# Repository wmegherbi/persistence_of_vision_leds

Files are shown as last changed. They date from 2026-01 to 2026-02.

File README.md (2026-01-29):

# persistence_of_vision_leds
Ce projet a pour objectif de concevoir et réaliser un système d’affichage basé sur la persistance rétinienne sur une barre de LEDs en rotation. En exploitant la persistance rétinienne de l’œil humain, le système permet d’afficher des images fixes ou animées dans l’espace à partir d’un nombre limité de LEDs disposées sur une structure rotative.

Ce projet se divise en trois parties différentes : 
- Partie Mécanique : plans et schémas du système complet ainsi que des impressions 3D 
- Partie LEDs : contrôle, alimentation des LEDs et traitement d'image via la Raspberry Pi située dans la partie rotative
- Partie Moteur : contrôle, alimentation du moteur et mise en place de l'interface de contrôle du moteur via la Raspberry Pi située dans la partie statique

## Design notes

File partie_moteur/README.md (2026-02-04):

# PARTIE MOTEUR

## Contrôle moteur et mesure de vitesse par capteur Hall (Raspberry Pi)

Ce projet permet de :
- piloter un moteur via PWM (50 Hz)
- mesurer la vitesse de rotation avec un capteur à effet Hall
- générer une impulsion matérielle '1 tour' sur un GPIO
- superviser le système via une interface web

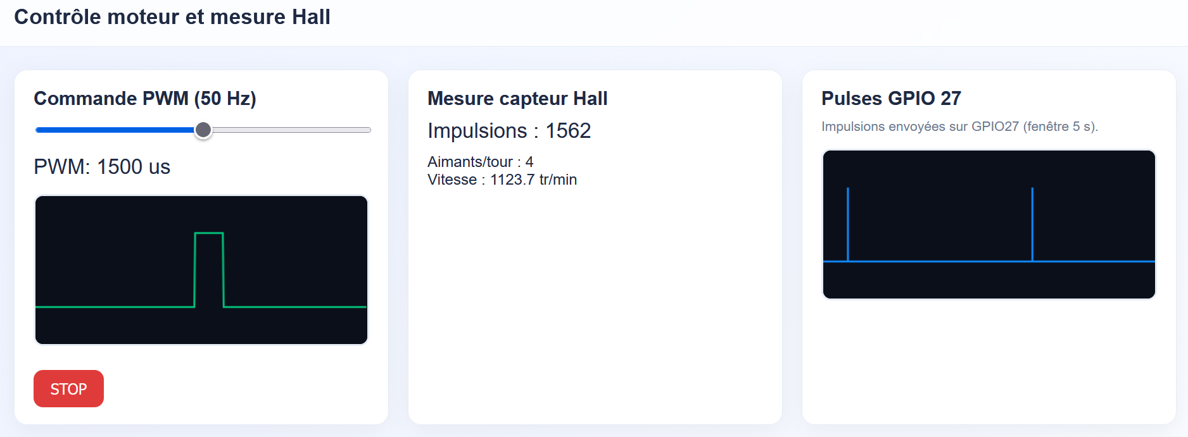
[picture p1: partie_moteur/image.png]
Interface de contrôle


---
## Table des matières

1. [Architecture](#architecture)
2. [Matériel requis](#matériel-requis)
   - [Connexions GPIO](#connexions-gpio)
3. [Installation](#installation)
   - [Installer pigpio](#installer-pigpio)
   - [Installer les dépendances Python](#2-installer-les-dependances-python)
4. [Utilisation](#utilisation)
   - [Lancer le programme](#lancer-le-programme)
   - [Accéder à l'interface web](#acceder-a-linterface-web)
5. [Fonctionnalités détaillées](#fonctionnalités)
6. [Fonctionnement interne](#fonctionnement-interne-résumé)
7. [Remarques](#remarques)

## Architecture

- pigpiod : gestion temps réel des GPIO (PWM)
- Python :  contrôle et géstion des données
- Flask : serveur web
- HTML / JavaScript : interface web

```` bash
partie_moteur/
├── web3_control.py    # Cœur du système : contrôle moteur, gestion capteur Hall, API Flask
├── static/
│   ├── app.js          # Logique front-end (graphiques, interactions)
│   └── style.css       # Styles de l'interface utilisateur
└── templates/
    └── index.html      # Template HTML principal (interface de contrôle)
````
---

## Matériel requis

### Composants principaux
- **Raspberry Pi** avec **Raspberry Pi OS** 
- **Capteur à effet Hall** (ex: US5881, A3144 ou DRV5055) pour la détection des tours
- **Moteur brushless A2212 930KV** + **ESC 30A** (compatible PWM 50Hz)
- **Aimants**  à fixer sur roue pour déclencher le capteur Hall

### Connexions GPIO

| GPIO Raspberry Pi | Fonction | Détails |
|---|---|---|
| GPIO 18 | Sortie PWM (commande moteur)  | Connecté à l'entrée PWM de l'ESC |
| GPIO 17 | Entrée capteur Hall | Configuré pour détecter les fronts |
| GPIO 27 | Sortie impulsion "1 tour" | Génère une impulsion de 100 µs à chaque tour complet du moteur |

---

## Installation

### Installer pigpio

```bash
sudo apt update
sudo apt install pigpio python3-pigpio
sudo pigpiod
```

### 2) Installer les dependances Python

```bash
pip3 install flask pigpio
```

## Utilisation

### Lancer le programme :

```bash
python3 web3_control.py
````

### Accéder à l'interface web :

```bash
http://<IP_DU_RASPBERRY>:5000
````

## Fonctionnalités

- Slider PWM (1000–2000 µs)
- Bouton STOP

Affichage :
- nombre d'impulsions Hall
- nombre d'aimants par tour
- vitesse en tr/min
- visualisation PWM et impulsions '1 tour'

## Fonctionnement interne (résumé)

- Les fronts du capteur Hall sont traités par un callback pigpio
- Les données partagées sont protégées par un lock (thread safety)
- La vitesse est calculée via une fenêtre glissante de timestamps de 5 secondes
- Une impulsion courte (100 µs) est générée sur GPIO27 à chaque tour complet (quand 4 fronts sont déctetés du capteur effet hall)

### Flux de Données
1. **Capteur Hall → Raspberry Pi** :
   - Détection des fronts via `pigpio.callback()` (dans `web3_control.py`)
   - Stockage des timestamps dans `edge_times[]`

2. **Raspberry Pi → Interface Web** :
   - Données exposées via les endpoints Flask :
     - `/api/hall` (compteur, RPM)
     - `/api/pulse` (timestamps des impulsions)
   - Mise à jour en temps réel via JavaScript (`static/app.js`)

3. **Interface Web → Moteur** :
   - Contrôle PWM via le slider (POST sur `/set_live`)
   - Arrêt d'urgence (POST sur `/stop`)

## Remarques

- pigpiod doit être lancé avant le script
``` bash
sudo pigpiod
```

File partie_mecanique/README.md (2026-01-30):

# PARTIE MECANIQUE

### Pièce 3D
Les pièces 3D ont été modélisées via Onshape, et disponible au format STL.

Stator : 
- ``main.stl`` support principal fixé à un trépied. 

Rotor : 
- ``petite_roue.stl`` roue dentée fixée au moteur. 
- ``grande_roue.stl`` roue principale.  
- ``couvercle.stl`` fixé à la grande roue. 
- [courroie](https://www.amazon.fr/sourcing-map-Courroie-distribution-caoutchouc/dp/B0DSR3P59V/ref=sr_1_4?__mk_fr_FR=ÅMÅŽÕÑ&crid=2DVCB6ZJ2Z6N6&dib=eyJ2IjoiMSJ9.INokD1g1XKGq4FjiK4KJ-2DFuZPBLBakq1pM_ikAQQW-i8_wvu6zflLYD9bUancVo1O1l0KUpVF_Tc12299VBfvdVWGJqAfd7dZ5Z0dowRu1OleMIxkBsCXyfrw_BsMGcycEjID_bXYTH-4Jm1so129zpuPP06CmUVDd1TbQXxbmJKklR36qcrfXnCtGEjsZ-37gbQdMV0VhXsDEZqvy0kOxExp_DtmuPP1F3U7picrk7hs-b8qVLdveGdYnYE3JuToG5yF9XXBt19ypSJsxIJoUYEDpVoUJI-cyxjdedZ8.aslACeUXgRTCYPRULSt5mBXesOI6mXxBFWhpa6HJw2Y&dib_tag=se&keywords=courroie+dentée+pas+5+mm+610+mm&qid=1767950807&sprefix=courroie+dentée+pas+5+mm+6010+mm%2Caps%2C284&sr=8-4) pour la transmission. 

## Description du support

``main`` est le support principal qui s'attache au trépied. La pièce est sous-dimensionnée volontairement au niveau du trépied afin d'assurer une meilleur stabilité, il est normal qu'il faille forcer légèrement pour la rentrer dans le trépied. 
Au dos de la pièce il y a un emplacement pour la carte Raspberry Pi qui contrôle le moteur, des emplacements sont prévus pour visser la carte. 
Le moteur se place en bas dans son emplacement prévu, Il se visse par l'arrière, les espacements entre les vis ne sont pas les mêmes horizontalement et verticalement, vérifiez le sens. 
Le capteur à effet Hall est collé sur le côté de la pièce afin de ne pas gêné les câbles et être suffisament près des aimants placés sur la roue. 

#### Support d'axe

Le support d'axe correspond à la partie supérieur de la pièce. Ce tube acceuille des [roulements à billes](https://www.123roulement.com/roulement-palier/roulement-bille/simple-rangee/6005-2rsh-skf) de diamètre intérieur 25 mm et 47 mm de diamètre extérieur. Pour assurer que les roulements à billes ne glisse pas hors du support pendant que le système est en marche il faut ajouter des vis dans les trous creusés sur le dessus de la pièce. Le slip ring se fixe au dos du support d'axe. 

## Transmission mécanique
La ``petite_roue`` est fixée au moteur et entraîne la [courroie](https://www.amazon.fr/sourcing-map-Courroie-distribution-caoutchouc/dp/B0DSR3P59V/ref=sr_1_4?__mk_fr_FR=ÅMÅŽÕÑ&crid=2DVCB6ZJ2Z6N6&dib=eyJ2IjoiMSJ9.INokD1g1XKGq4FjiK4KJ-2DFuZPBLBakq1pM_ikAQQW-i8_wvu6zflLYD9bUancVo1O1l0KUpVF_Tc12299VBfvdVWGJqAfd7dZ5Z0dowRu1OleMIxkBsCXyfrw_BsMGcycEjID_bXYTH-4Jm1so129zpuPP06CmUVDd1TbQXxbmJKklR36qcrfXnCtGEjsZ-37gbQdMV0VhXsDEZqvy0kOxExp_DtmuPP1F3U7picrk7hs-b8qVLdveGdYnYE3JuToG5yF9XXBt19ypSJsxIJoUYEDpVoUJI-cyxjdedZ8.aslACeUXgRTCYPRULSt5mBXesOI6mXxBFWhpa6HJw2Y&dib_tag=se&keywords=courroie+dentée+pas+5+mm+610+mm&qid=1767950807&sprefix=courroie+dentée+pas+5+mm+6010+mm%2Caps%2C284&sr=8-4) qui entraîne la ``grande_roue``. Le ``couvercle`` est vissé sur la grande roue et tient les profilés en aluminium avec [les bandeaux de LEDs](https://fr.aliexpress.com/item/4001201679511.html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€%216%2C79€%21%21%21%21%21%40211b61bb17643396735751664eb65b%2110000015284474061%21btfpre%21%21%21%211%210%21&afTraceInfo=4001201679511__pc__c_ppc_item_bridge_pc_main__rdjCUwP__1764339673682&gatewayAdapt=glo2fra). Le rapport de réduction entre les roues est d'environ 8.5. 

Courroie :
* Longueur: 610 mm
* Largeur: 15 mm
* Pas: 5 mm

Petite Roue : 
* Diamètre: 19 mm (à l'extérieur des dents)
* Largeur: 30 mm
* Pas: 5 mm

Grande roue : 
* Diamètre: 161 mm (à l'extérieur des dents)
* Largeur: 22 mm
* Pas: 5 mm
* Longueur de l'axe de rotation: 84.4 mm

L'axe de rotation est percé afin d'acceuillir les câbles sortant du slip ring. Ces câbles servent à l'alimentation de la carte Raspberry Pi et des bandeaux de LEDs ainsi que la transmission du signal généré par le capteur à effet Hall. La carte Raspberry Pi est vissé dans le compartiment au centre de la roue.

Le ``couvercle`` recouvre la Raspberry Pi de la grande roue, il est troué pour laisser les câbles qui font la communication entre les bandeaux de LED et la carte Raspberry Pi. [Les profilés en aluminium](https://www.leroymerlin.fr/produits/profile-u-aluminium-anodise-mat-standers-h-10-x-l-15-x-ep-1-mm-l-1-m-87477956.html) y sont vissés en son centre. Sur ces profilés sont attachés [les bandeaux de LEDs](https://fr.aliexpress.com/item/4001201679511.html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€%216%2C79€%21%21%21%21%21%40211b61bb17643396735751664eb65b%2110000015284474061%21btfpre%21%21%21%211%210%21&afTraceInfo=4001201679511__pc__c_ppc_item_bridge_pc_main__rdjCUwP__1764339673682&gatewayAdapt=glo2fra). Des serre flex permettent de maintenir les LEDs et leurs câbles sur les profilés.

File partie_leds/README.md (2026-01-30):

# Dans ce dossier, vous trouverez tout ce qu'il faut savoir pour faire fonctionner les LEDs sur le système

## Sommaire
- [Partie 1 : Connexion avec la Raspberry Pi](#partie-1--connexion-avec-la-raspberry-pi)
- [Partie 2 : Gestion des LEDs](#partie-2--gestion-des-leds)
  - [Interfaces SPI](#interfaces-spi)
  - [Remarques](#remarques)
- [Partie 3 : Comment setup une Raspberry Pi toute neuve](#partie-3--comment-setup-une-raspberry-pi-toute-neuve)

## Partie 1 : Connexion avec la Raspberry Pi

La Raspberry Pi est alimentée via le 5 V provenant du slip ring, lui-même relié à la prise secteur. Cette même alimentation alimente également les LEDs via des connecteurs situés aux quatre coins de la roue.

Pour lancer le programme sur la Raspberry Pi, on se connecte en SSH depuis un PC connecté au même réseau. Pour la première connexion, nous conseillons d’utiliser l’interface graphique de la Raspberry Pi afin de configurer les paramètres réseau (nom du réseau et mot de passe) à l’aide d’un clavier, d’une souris et d’un écran connecté en HDMI à la carte.  
Notez également l’adresse IP de la Raspberry Pi une fois connectée au réseau, afin de configurer la liaison SSH.

### Nom d’utilisateur et mot de passe
Le nom d’utilisateur et le mot de passe de cette Raspberry Pi sont respectivement :  
**nom d’utilisateur : `se`**  
**mot de passe : `se`**

Une fois connecté en SSH, placez-vous dans le répertoire de travail et activez l’environnement virtuel Python dans lequel sont installées les bibliothèques nécessaires :

```bash
cd pr/
source venv/bin/activate
```

Notez qu’à chaque redémarrage de la carte, l’environnement virtuel `venv` doit être réactivé.

Il ne reste plus qu’à lancer le programme de votre choix. Ici, nous utiliserons `logon.py` qui est notre code le plus abouti. Il permet d'afficher l'image logo.jpg, le logo Raspberry Pi. Les autres fichiers dans le repertoire /tests sont des tests effectués tout le long du projet pour s'assurer du bon fonctionnement des LEDs et de la connectivité.

```bash
python3 logon.py
```

## Partie 2 : Gestion des LEDs

### Interfaces SPI

Nous avons besoin de **quatre interfaces SPI indépendantes**, qui doivent être présentes dans `/dev` afin d’être détectées par la bibliothèque `dotstar`.  
Pour leur mise en place, voir la section [Partie 3 : Comment setup une Raspberry Pi toute neuve](#partie-3--comment-setup-une-raspberry-pi-toute-neuve).

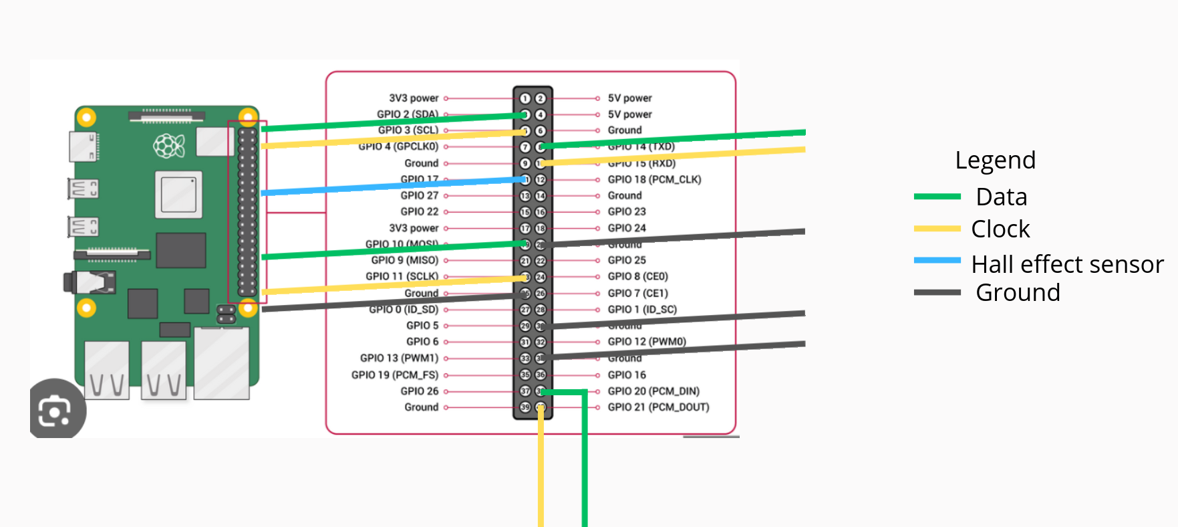
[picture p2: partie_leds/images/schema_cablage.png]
Branchements des LEDs sur la Raspberry Pi


Dans notre programme `logon.py`, les bandeaux de LEDs sont déclarés comme suit, ce qui correspond aux connexions GPIO visibles sur l’image ci-dessus :

```python
# East
strip_e = adafruit_dotstar.DotStar(board.D3, board.D2, NUM_LEDS, brightness=0.1, auto_write=False)
# North
strip_n = adafruit_dotstar.DotStar(board.D11, board.D10, NUM_LEDS, brightness=0.1, auto_write=False)
# West
strip_w = adafruit_dotstar.DotStar(board.D21, board.D20, NUM_LEDS, brightness=0.1, auto_write=False)
# South
strip_s = adafruit_dotstar.DotStar(board.D15, board.D14, NUM_LEDS, brightness=0.1, auto_write=False)
```

Lors du câblage, il est important de vérifier quels GPIO sont connectés à quels bandeaux de LEDs, par exemple à l’aide d’un programme qui allume chaque bandeau avec une couleur différente afin de les identifier. Des erreurs ou inversions sont possibles.

### Remarques

- Le temps entre chaque itération de la boucle (ce qui définit la fréquence de rafraîchissement des LEDs) n’est modifiable que dans le programme, via la variable `dt`.
- Il n’existe pas de moyen direct d’éteindre les LEDs via le code, à part afficher une image noire ou couper puis rétablir l’alimentation électrique.
- Plusieurs améliorations du code sont possibles :
  - augmenter le pas angulaire à 2° ;
  - ne rafraîchir qu’un seul bandeau de LEDs à la fois au lieu des quatre ;
  - ajouter un `try/except` pour éteindre toutes les LEDs lors d’une interruption du programme via `KeyboardInterrupt` ;
  - créer une interface permettant de faire varier dynamiquement la fréquence de rafraîchissement des LEDs.

## Partie 3 : Comment setup une Raspberry Pi toute neuve

Dans le cas où l’OS doit être réinstallé sur la Raspberry Pi, ou en cas de changement de carte, cette partie explique comment tout configurer afin de faire fonctionner le programme.

Tout d’abord, il faut activer les interfaces SPI nécessaires. Certaines combinaisons d’interfaces SPI ne fonctionnent pas ensemble ; nous avons dû procéder par essais/erreurs afin de trouver une combinaison de quatre interfaces fonctionnelles.

Pour les activer, on modifie directement le fichier `config.txt`. Selon la version de l’OS installée, son emplacement peut varier :

```bash
sudo nano /boot/firmware/config.txt
```

À la fin du fichier, ajouter les lignes suivantes :

```ini
dtoverlay=spi0-1cs
dtoverlay=spi6-1cs
dtoverlay=spi5-1cs
dtoverlay=spi3-1cs
```

Redémarrer ensuite la carte :

```bash
sudo reboot
```

On peut vérifier que les quatre interfaces SPI sont bien visibles dans le répertoire `/dev` :

```bash
ls /dev/spi*
```

Ensuite, créer un dossier de travail, mettre le système à jour et installer Python :

```bash
sudo apt update
sudo apt upgrade -y
sudo apt install -y python3 python3-pip python3-venv python3-dev
```

Enfin, créer l’environnement virtuel Python et installer les bibliothèques nécessaires :

```bash
mkdir pr
cd pr/
python3 -m venv venv
source venv/bin/activate
pip install --upgrade pip
pip install adafruit-circuitpython-dotstar
pip install adafruit-blinka
pip install pillow
```

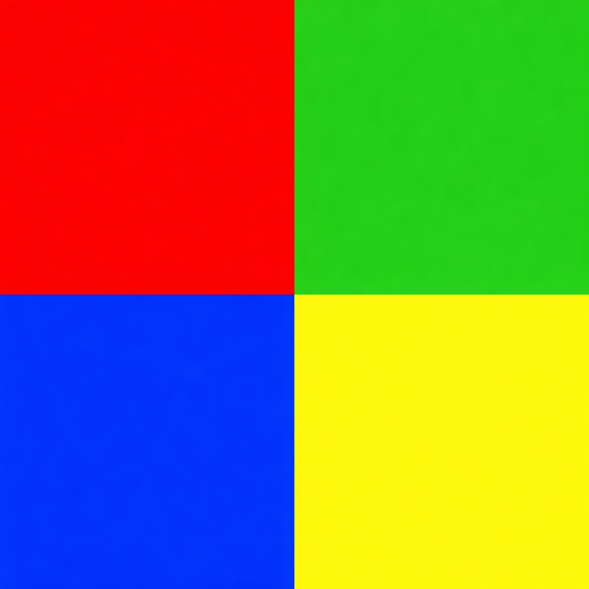
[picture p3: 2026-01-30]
partie_leds/win.png

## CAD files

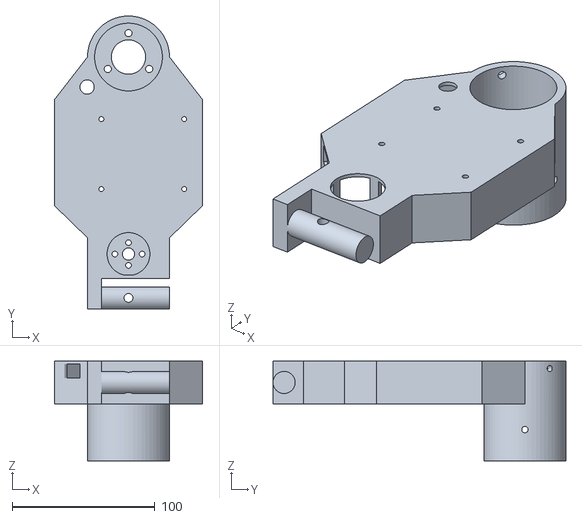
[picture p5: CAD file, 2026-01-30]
partie_mecanique/main.stl
104.0 x 205.2 x 70.0

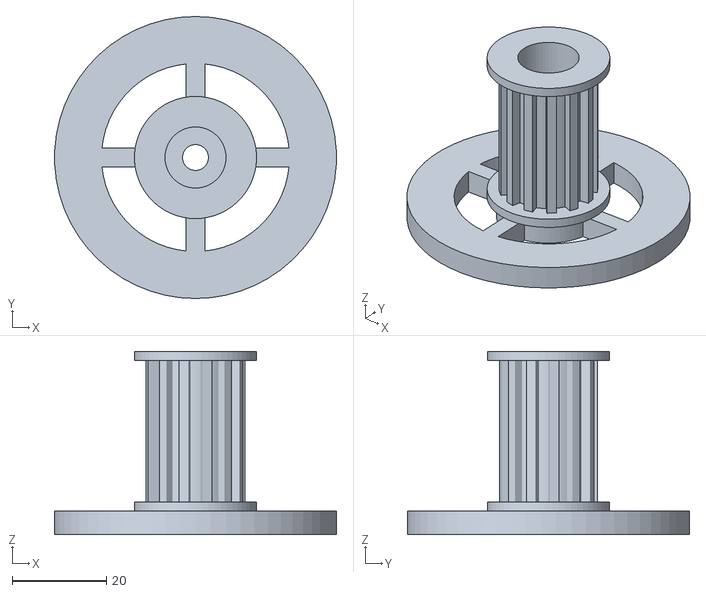
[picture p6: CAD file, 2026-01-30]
partie_mecanique/petite_roue.stl
60.0 x 60.0 x 39.0

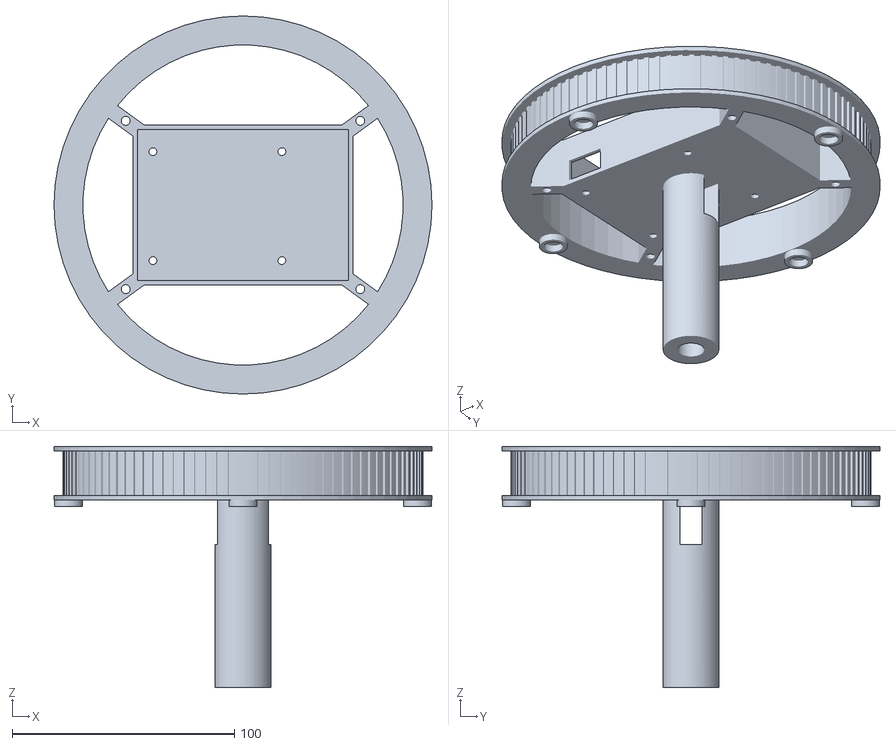
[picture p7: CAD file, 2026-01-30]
partie_mecanique/grande_roue.stl
170.0 x 170.0 x 108.4

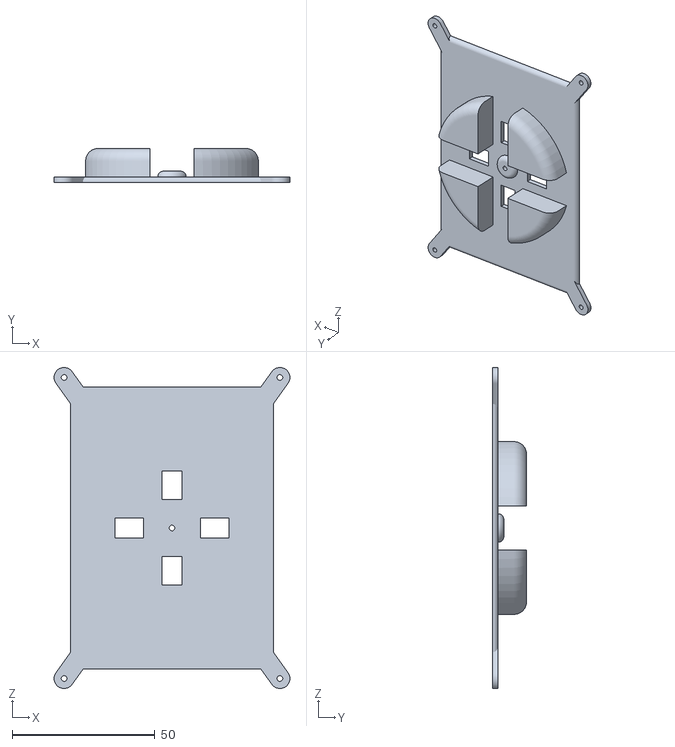
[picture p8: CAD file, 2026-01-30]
partie_mecanique/couvercle.stl
82.7 x 12.0 x 112.5

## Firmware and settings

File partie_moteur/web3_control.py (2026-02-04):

import threading
import time

from flask import Flask, render_template, request, jsonify
import pigpio

GPIO_PWM = 18
GPIO_HALL = 17
GPIO_REV_PULSE = 27

MAX_EDGES = 20
REV_PULSE_US = 100
MAX_PULSES = 200
PULSE_WINDOW_S = 5.0

app = Flask(__name__)

lock = threading.Lock()
hall_count = 0
edge_times = []
pulse_times = []
magnets_per_rev = 4
current_pwm = 1000

pi = pigpio.pi()
if not pi.connected:
    raise Exception("pigpiod n'est pas lance : sudo pigpiod")

pi.set_mode(GPIO_HALL, pigpio.INPUT)
pi.set_pull_up_down(GPIO_HALL, pigpio.PUD_UP)

pi.set_mode(GPIO_REV_PULSE, pigpio.OUTPUT)
pi.write(GPIO_REV_PULSE, 0)


def hall_callback(gpio, level, tick):
    global hall_count, edge_times, pulse_times

    now = time.time()
    with lock:
        if level == 1:
            hall_count += 1
            edge_times.append(now)
            if len(edge_times) > MAX_EDGES:
                edge_times.pop(0)

            if magnets_per_rev > 0 and hall_count % magnets_per_rev == 0:
                pi.gpio_trigger(GPIO_REV_PULSE, REV_PULSE_US, 1)
                pulse_times.append(now)
                if len(pulse_times) > MAX_PULSES:
                    pulse_times.pop(0)


cb = pi.callback(GPIO_HALL, pigpio.EITHER_EDGE, hall_callback)


@app.route("/")
def index():
    with lock:
        return render_template(
            "index.html",
            value=current_pwm,
            hall_count=hall_count,
            magnets_per_rev=magnets_per_rev,
        )


@app.route("/set_live", methods=["POST"])
def set_live():
    global current_pwm
    pwm = int(request.form["pwm"])
    current_pwm = pwm
    pi.set_servo_pulsewidth(GPIO_PWM, pwm)
    return ""


@app.route("/stop", methods=["POST"])
def stop():
    global current_pwm
    current_pwm = 1000
    pi.set_servo_pulsewidth(GPIO_PWM, 1000)
    with lock:
        return render_template(
            "index.html",
            value=current_pwm,
            hall_count=hall_count,
            magnets_per_rev=magnets_per_rev,
        )


@app.route("/api/hall")
def hall_api():
    with lock:
        rpm = 0
        if magnets_per_rev > 0 and len(edge_times) >= 2:
            period = (edge_times[-1] - edge_times[0]) / (len(edge_times) - 1)
            if period > 0:
                rpm = round(60 / (period * magnets_per_rev), 1)

        return jsonify({
            "count": hall_count,
            "magnets_per_rev": magnets_per_rev,
            "rpm": rpm,
        })


@app.route("/api/pulse")
def pulse_api():
    with lock:
        now = time.time()
        recent = [t for t in pulse_times if now - t <= PULSE_WINDOW_S]
        pulse_times[:] = recent
        return jsonify([{"t": t} for t in recent])


def cleanup():
    cb.cancel()
    pi.stop()


if __name__ == "__main__":
    try:
        app.run(host="0.0.0.0", port=5000)
    finally:
        cleanup()

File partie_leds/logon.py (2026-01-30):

from PIL import Image
import math
import time
import board
import adafruit_dotstar
    
dt =  0.01
# ==========================
# Capteur Hall 
# ==========================

# ==========================
# Configuration
# ==========================
NUM_LEDS = 72
sensor = 0  # passera à 1 quand la position de référence est atteinte
#ok
# East
strip_e = adafruit_dotstar.DotStar(board.D3, board.D2, NUM_LEDS, brightness=0.1, auto_write=False)
# North
strip_n = adafruit_dotstar.DotStar(board.D11, board.D10, NUM_LEDS, brightness=0.1, auto_write=False)
# West
strip_w = adafruit_dotstar.DotStar(board.D21, board.D20, NUM_LEDS, brightness=0.1, auto_write=False)
# South
strip_s = adafruit_dotstar.DotStar(board.D15, board.D14, NUM_LEDS, brightness=0.1, auto_write=False)

# ==========================
# Image
# ==========================
img = Image.open("logo.jpg").resize((144, 144)).convert("RGB")
width, height = img.size
center_x, center_y = width // 2, height // 2

# ==========================
# Polar -> pixel
# ==========================
def get_pixel_from_polar(angle_deg, radius):
    angle_rad = math.radians(angle_deg)
    x = int(center_x + radius * math.cos(angle_rad))
    y = int(center_y - radius * math.sin(angle_rad))  
    if 0 <= x < width and 0 <= y < height:
        return img.getpixel((x, y))
    return (0, 0, 0)

# ==========================
# Displays a strip
# ==========================
def display_strip(strip, angle_deg):
    for r in range(NUM_LEDS):
        strip[r] = get_pixel_from_polar(angle_deg, NUM_LEDS -1 - r)
    strip.show()

# = Main loop
# ==========================
global_angle = 0

while True:

    # --- Reference position : angle = 0 ---
    if sensor == 1:
        global_angle = 0
        sensor = 0  

    # --- Processing angles ---
    angle_e = (global_angle + 0) % 360
    angle_n = (global_angle + 90) % 360
    angle_w = (global_angle + 180) % 360
    angle_s = (global_angle + 270) % 360

    # --- Displaying in real time ---x
    display_strip(strip_e, angle_e)
    display_strip(strip_n, angle_n)
    display_strip(strip_w, angle_w)
    display_strip(strip_s, angle_s)

    # --- Rotation ---
    global_angle = (global_angle + 1) % 360
    time.sleep(dt)

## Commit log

2026-01-30 add 3D Model
    [couvercle.stl, grande_roue.stl, main.stl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]
2026-01-30 quelques test de la comm SPI en langage C
